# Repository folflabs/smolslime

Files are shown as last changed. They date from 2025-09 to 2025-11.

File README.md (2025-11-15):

# Folf Labs SlimeVR Trackers [WIP]
Unofficial (DIY) Smol SlimeVR-compatible trackers powered by Nordic nRF52840 SoC and ICM-45686 IMU. 

## SmolBoard


SmolBoard is a PCB that sits on top of the SuperMini nRF52840 as an alternative to the [Stacked Slime](https://docs.slimevr.dev/smol-slimes/hardware/smol-tracker.html). It contains the ICM-45686 IMU, a 32.768kHz crystal, a battery switch, and two buttons: SW0 (user button) + RST (reset).

> [!NOTE]
> The battery switch physically disconnects the battery from the rest of the circuit. Keep it switched ON during charging, otherwise the battery won't charge.

> [!WARNING]
> On **rev 1**, the IMU and crystal are powered from the VCC pin.
> The recommended way is to power them through P0.31 (right below the VCC).
> Fix: jumper VCC and P0.31 on the SmolBoard, then solder just the P0.31 on the SuperMini.

### To-Do (Future Revision)
- [ ] Reduce the board width slightly to match the SuperMini
- [X] Power the IMU and crystal via P0.31

## Credits
The enclosure is inspired by Sorakage033's Cheesecake. I own a set of six Cheesecakes, and they're really well designed!

## License
This project is licensed under the [Creative Commons Attribution-NonCommercial 4.0](https://creativecommons.org/licenses/by-nc/4.0/).

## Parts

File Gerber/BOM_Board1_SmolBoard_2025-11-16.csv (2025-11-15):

No. | Quantity | Comment | Designator | Footprint | Value | Manufacturer Part | Manufacturer | Supplier Part | Supplier
1 | 2 | 100nF | C1,C2 | C0402 | 100nF |  |  | C1525
2 | 2 | HDR-M_2.54_1x11P | H1,H2 | HDR-TH_11P-P2.54-V-M
3 | 4 | 10kΩ | R1,R2,R3,R4 | R0402 | 10kΩ | 0402WGF1002TCE | UNI-ROYAL(厚声) | C25744 | LCSC
4 | 2 | TS-1088-AR02016 | RST,SW0 | SW-SMD_L3.9-W3.0-P4.45 |  | TS-1088-AR02016 | XUNPU(讯普) | C720477 | LCSC
5 | 1 | ICM-45686 | U1 | LGA-14_L3.0-W2.5-P0.50-TL |  | ICM-45686 | TDK InvenSense(应美盛) | C22459454 | LCSC
6 | 1 | MSS12C02LS-BB2.0 | U2 | SW-SMD_MSS12C02LS-HB2.0-1 |  | MSS12C02LS-BB2.0 | SHOU HAN(首韩) | C3008585 | LCSC
7 | 1 | 32.768kHz | X1 | OSC-SMD_4P-L3.2-W2.5-BL-1 | 32.768kHz | TFOM32768K4RHKCNT2T | YJX(雅晶鑫) | C454609 | LCSC

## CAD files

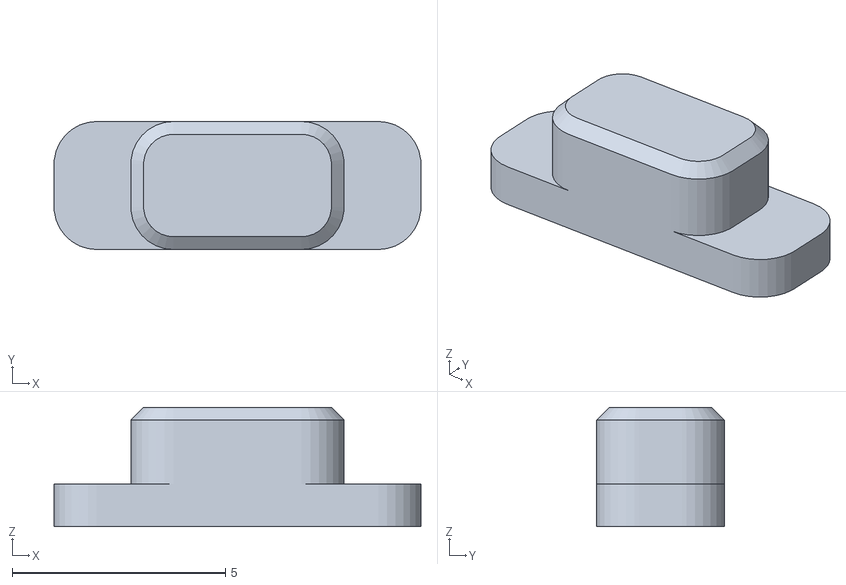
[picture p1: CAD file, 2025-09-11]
STLs/Tracker - Switch.stl
8.60 x 3.00 x 2.80

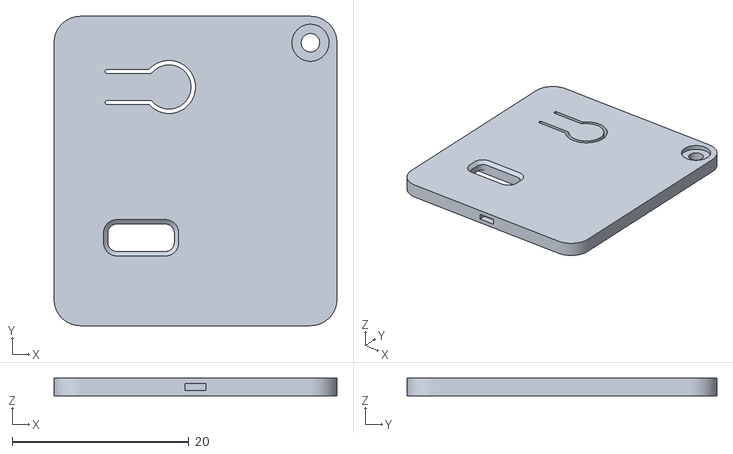
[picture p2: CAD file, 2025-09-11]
STLs/Tracker - Lid.stl
32.0 x 35.0 x 2.00

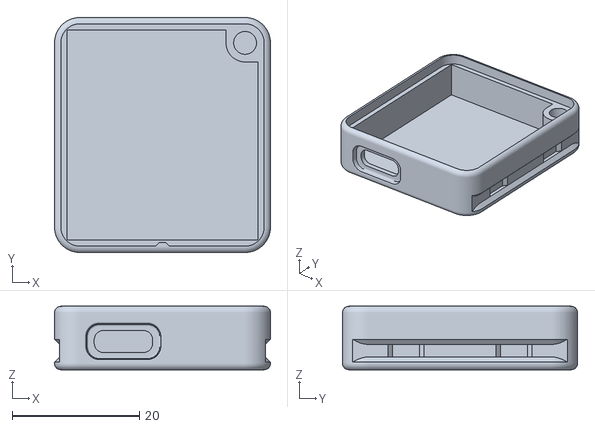
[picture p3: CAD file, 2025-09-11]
STLs/Tracker - Body.stl
34.0 x 37.0 x 10.0

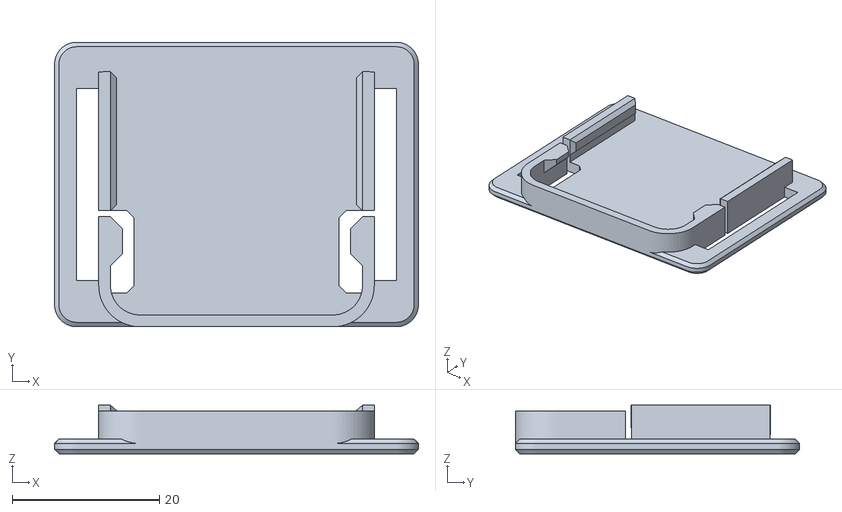
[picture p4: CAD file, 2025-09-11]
STLs/Tracker - Holder.stl
49.4 x 38.6 x 6.60

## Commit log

2025-09-11 Add tracker STLs
    [Tracker - Body.stl, Tracker - Holder.stl, Tracker - Lid.stl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]
2025-11-15 Add gerber files
    [BOM_Board1_SmolBoard_2025-11-16.csv, PickAndPlace_SmolBoard_2025-11-16.csv]
